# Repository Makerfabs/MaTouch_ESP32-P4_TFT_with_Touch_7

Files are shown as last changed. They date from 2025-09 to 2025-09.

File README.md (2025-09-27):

If you encounter the following error when compiling under Windows, please try enabling Windows long path support.
```txt
\MaTouch_ESP32-P4_TFT_with_Touch_7\examples\esp_brookesia_phone\managed_components\espressif__esp_wifi_remote\dummy_src.c.obj.d: No such file or directory
```

do :

```cmd
# Open PowerShell with administrator privileges
reg add "HKLM\SYSTEM\CurrentControlSet\Control\FileSystem" /v LongPathsEnabled /t REG_DWORD /d 1
```

Restart the system.

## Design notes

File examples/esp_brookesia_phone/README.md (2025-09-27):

# ESP_Brookesia Phone

[中文版本](./README_CN.md)

This example, based on [ESP_Brookesia](https://github.com/espressif/esp-brookesia), demonstrates an Android-like interface that includes many different applications. The example utilizes the development board's MIPI-DSI, MIPI-CSI, ESP32-C6, SD card, and audio interfaces. Based on this example, a use case can be created using ESP_Brookesia, enabling efficient development of multimedia applications.

## Getting Started

### ESP-IDF Required

- This example supports ESP-IDF release/v5.4 and later branches. By default, it runs on ESP-IDF release/v5.4.
- Please follow the [ESP-IDF Programming Guide](https://docs.espressif.com/projects/esp-idf/en/latest/esp32/get-started/index.html) to set up the development environment. **We highly recommend** you [Build Your First Project](https://docs.espressif.com/projects/esp-idf/en/latest/esp32/get-started/index.html#build-your-first-project) to get familiar with ESP-IDF and make sure the environment is set up correctly.

### Configuration

Run ``idf.py menuconfig`` and go to ``Board Support Package(ESP32-P4)``:

```
menuconfig > Component config > Board Support Package
```

To use the SD card and enable the "Recorder" APP, "Camera" APP, run ``idf.py menuconfig`` and then select ``Example Configurations`` > ``Enable SD Card``

## How to Use the Example

### Build and Flash the Example

Build the project and flash it to the board, then run monitor tool to view serial output (replace `PORT` with your board's serial port name):

```c
idf.py -p PORT flash monitor
```

To exit the serial monitor, type ``Ctrl-]``.

See the [ESP-IDF Getting Started Guide](https://docs.espressif.com/projects/esp-idf/en/latest/get-started/index.html) for full steps to configure and use ESP-IDF to build projects.

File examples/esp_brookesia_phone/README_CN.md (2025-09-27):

# ESP_Brookesia Phone

[英文版本](./README.md)

该示例基于 [ESP_Brookesia](https://github.com/espressif/esp-brookesia)，展示了一个类似 Android 的界面，其中包含许多不同的应用程序。该示例使用了开发板的 MIPI-DSI 接口、MIPI-CSI 接口、ESP32-C6、SD 卡和音频接口。基于此示例，可以基于 ESP_Brookesia 创建一个使用案例，从而高效开发多媒体应用程序。

## 快速入门

### ESP-IDF 要求

- 此示例支持 ESP-IDF release/v5.4 及以上版本。默认情况下，在 ESP-IDF release/v5.4 上运行。
- 请参照 [ESP-IDF 编程指南](https://docs.espressif.com/projects/esp-idf/zh_CN/latest/esp32/get-started/index.html) 设置开发环境。**强烈推荐** 通过 [编译第一个工程](https://docs.espressif.com/projects/esp-idf/zh_CN/latest/esp32/get-started/index.html#id8) 来熟悉 ESP-IDF，并确保环境设置正确。

### 配置

运行 ``idf.py menuconfig`` 并修改 ``Board Support Package(ESP32-P4)`` 配置：

```
menuconfig > Component config > Board Support Package
```

若要使用 SD 卡并启用 "Recorder" APP，“Camera” APP，请运行 ``idf.py menuconfig`` 然后选择 ``Example Configurations`` > ``Enable SD Card``

## 如何使用示例

### 编译和烧录示例

编译项目并将其烧录到开发板上，运行监视工具可查看串行端口输出（将 `PORT` 替换为所用开发板的串行端口名）：

```c
idf.py -p PORT flash monitor
```

输入``Ctrl-]`` 可退出串口监视。

有关配置和使用 ESP-IDF 来编译项目的完整步骤，请参阅 [ESP-IDF 快速入门指南](https://docs.espressif.com/projects/esp-idf/zh_CN/latest/esp32/get-started/index.html) 。

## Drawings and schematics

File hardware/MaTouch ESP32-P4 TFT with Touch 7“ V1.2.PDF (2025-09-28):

# MCU

# Mic&Speak

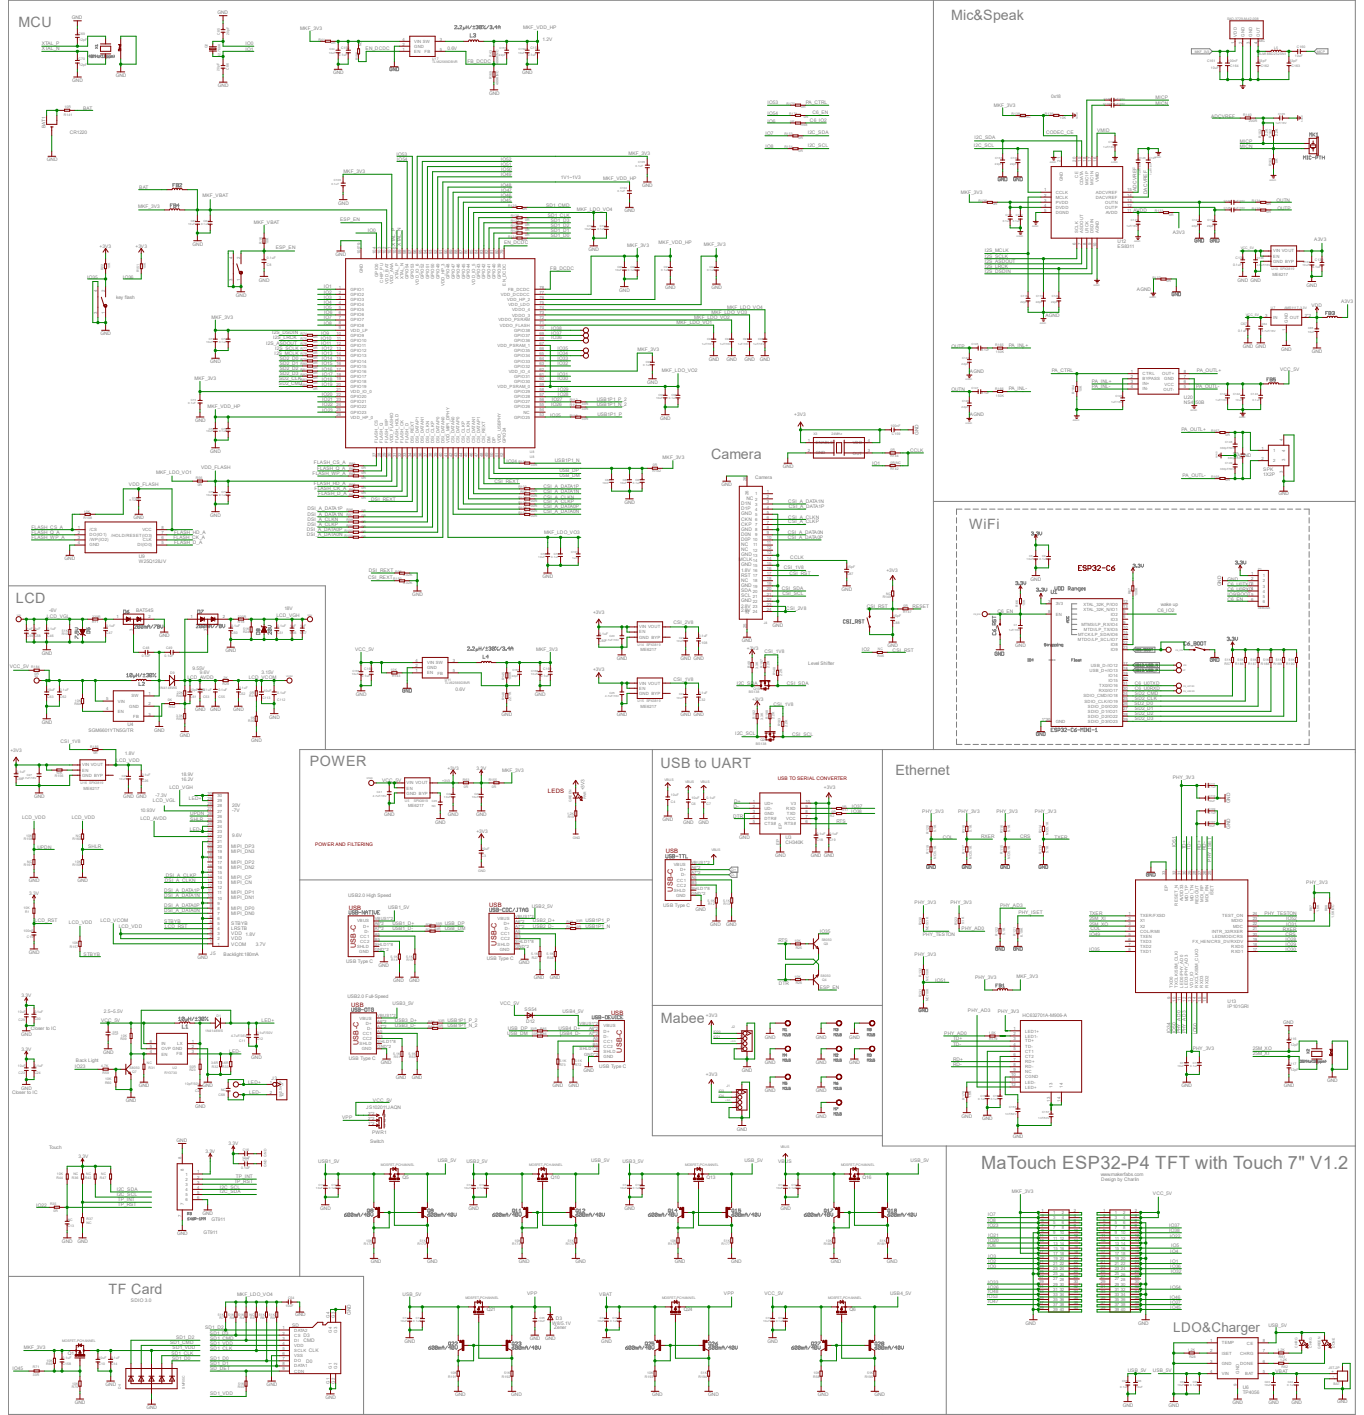
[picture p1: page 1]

USB TO SERIAL CONVERTER

GND
Design by Charlin MaTouch ESP32-P4 TFT with Touch 7" V1.2

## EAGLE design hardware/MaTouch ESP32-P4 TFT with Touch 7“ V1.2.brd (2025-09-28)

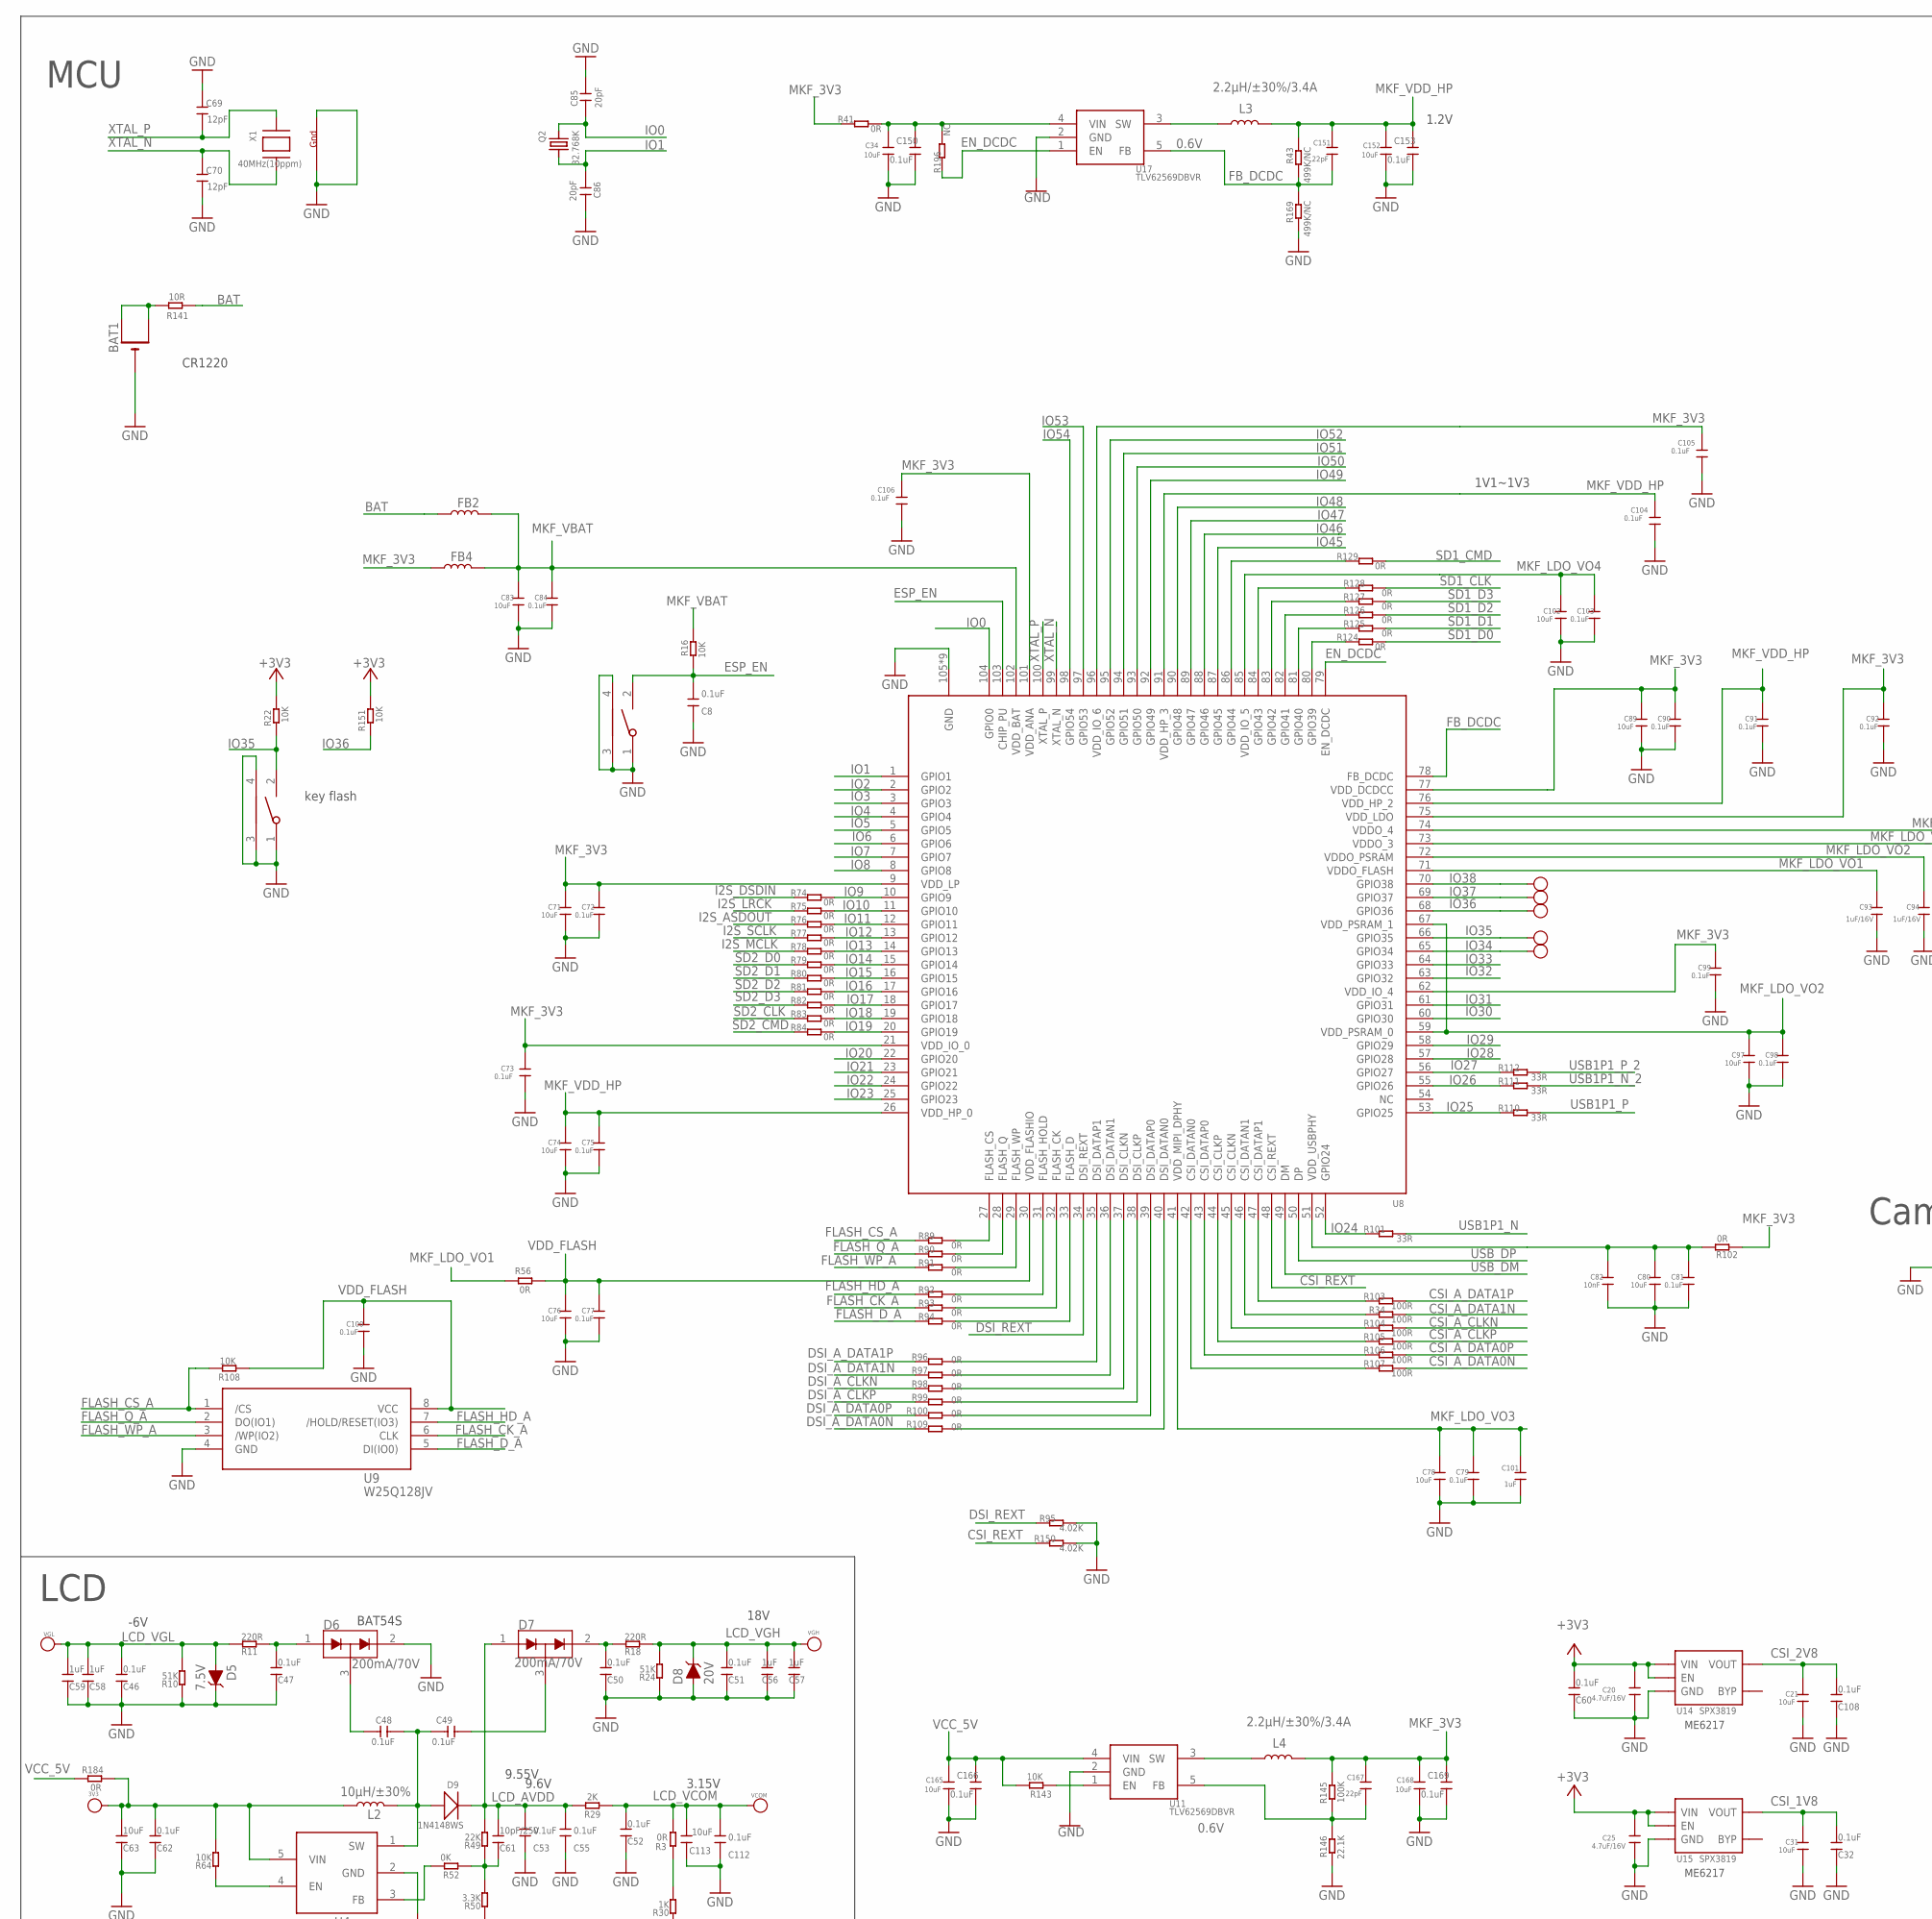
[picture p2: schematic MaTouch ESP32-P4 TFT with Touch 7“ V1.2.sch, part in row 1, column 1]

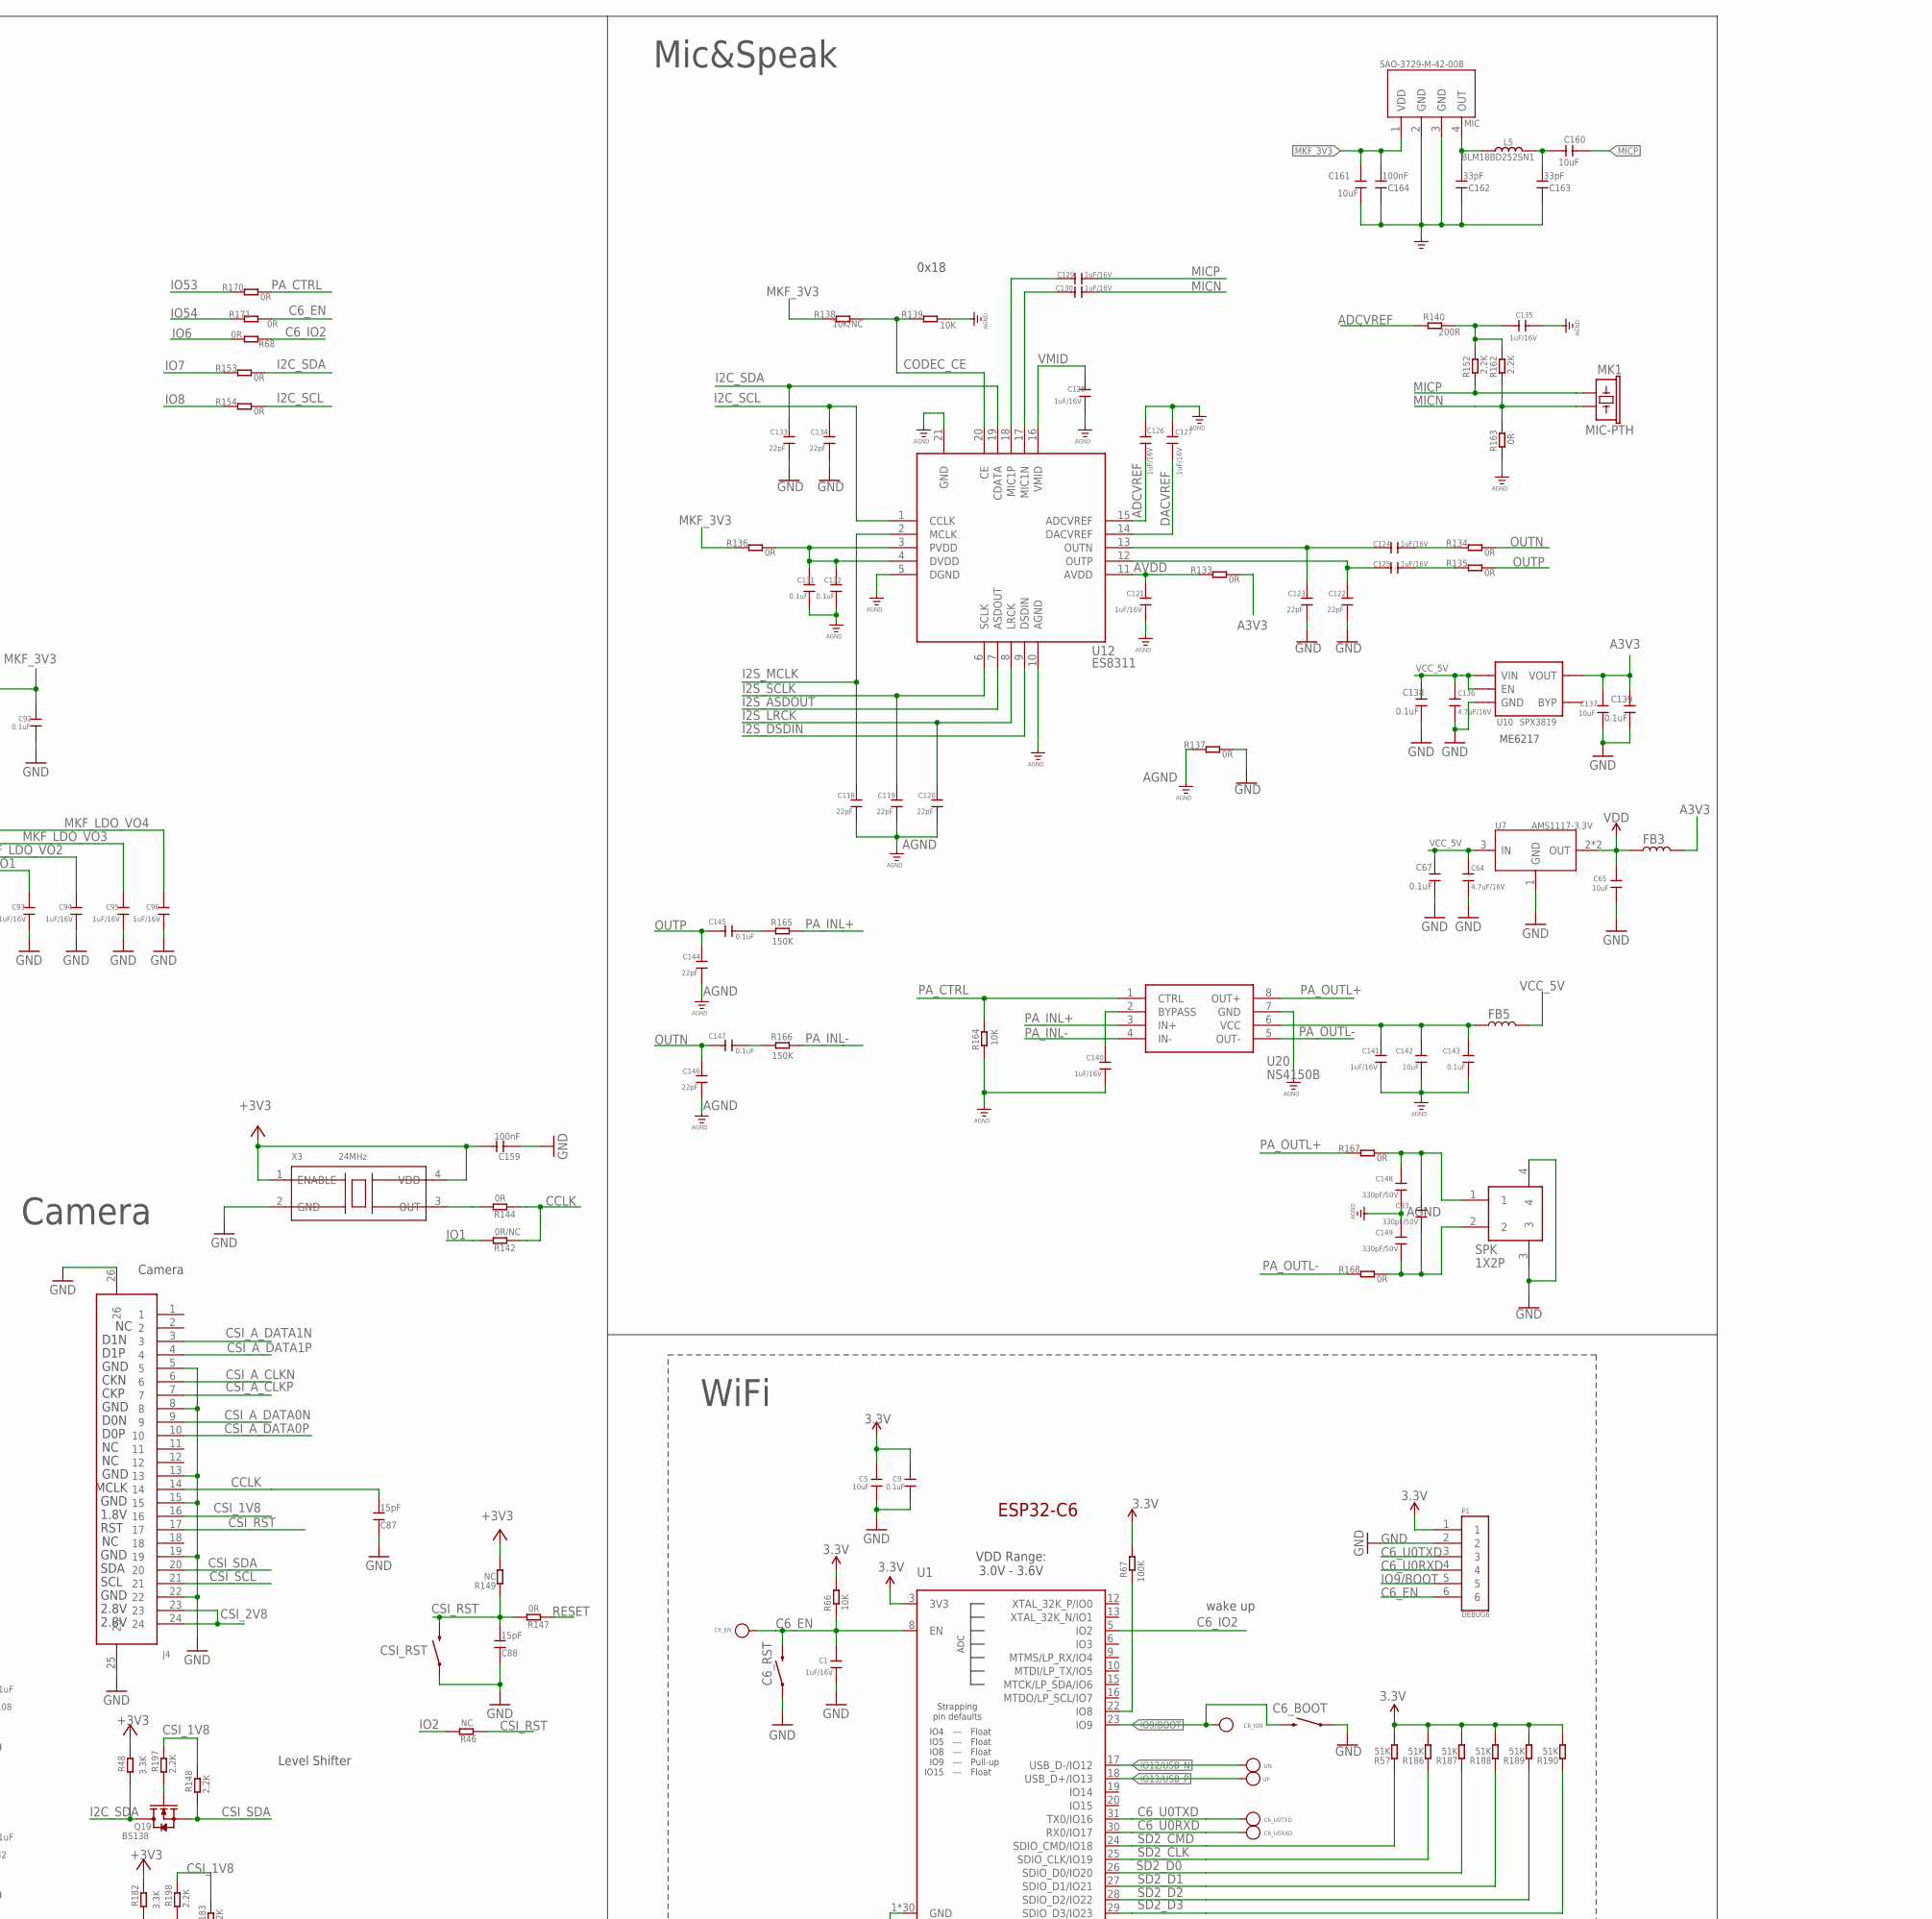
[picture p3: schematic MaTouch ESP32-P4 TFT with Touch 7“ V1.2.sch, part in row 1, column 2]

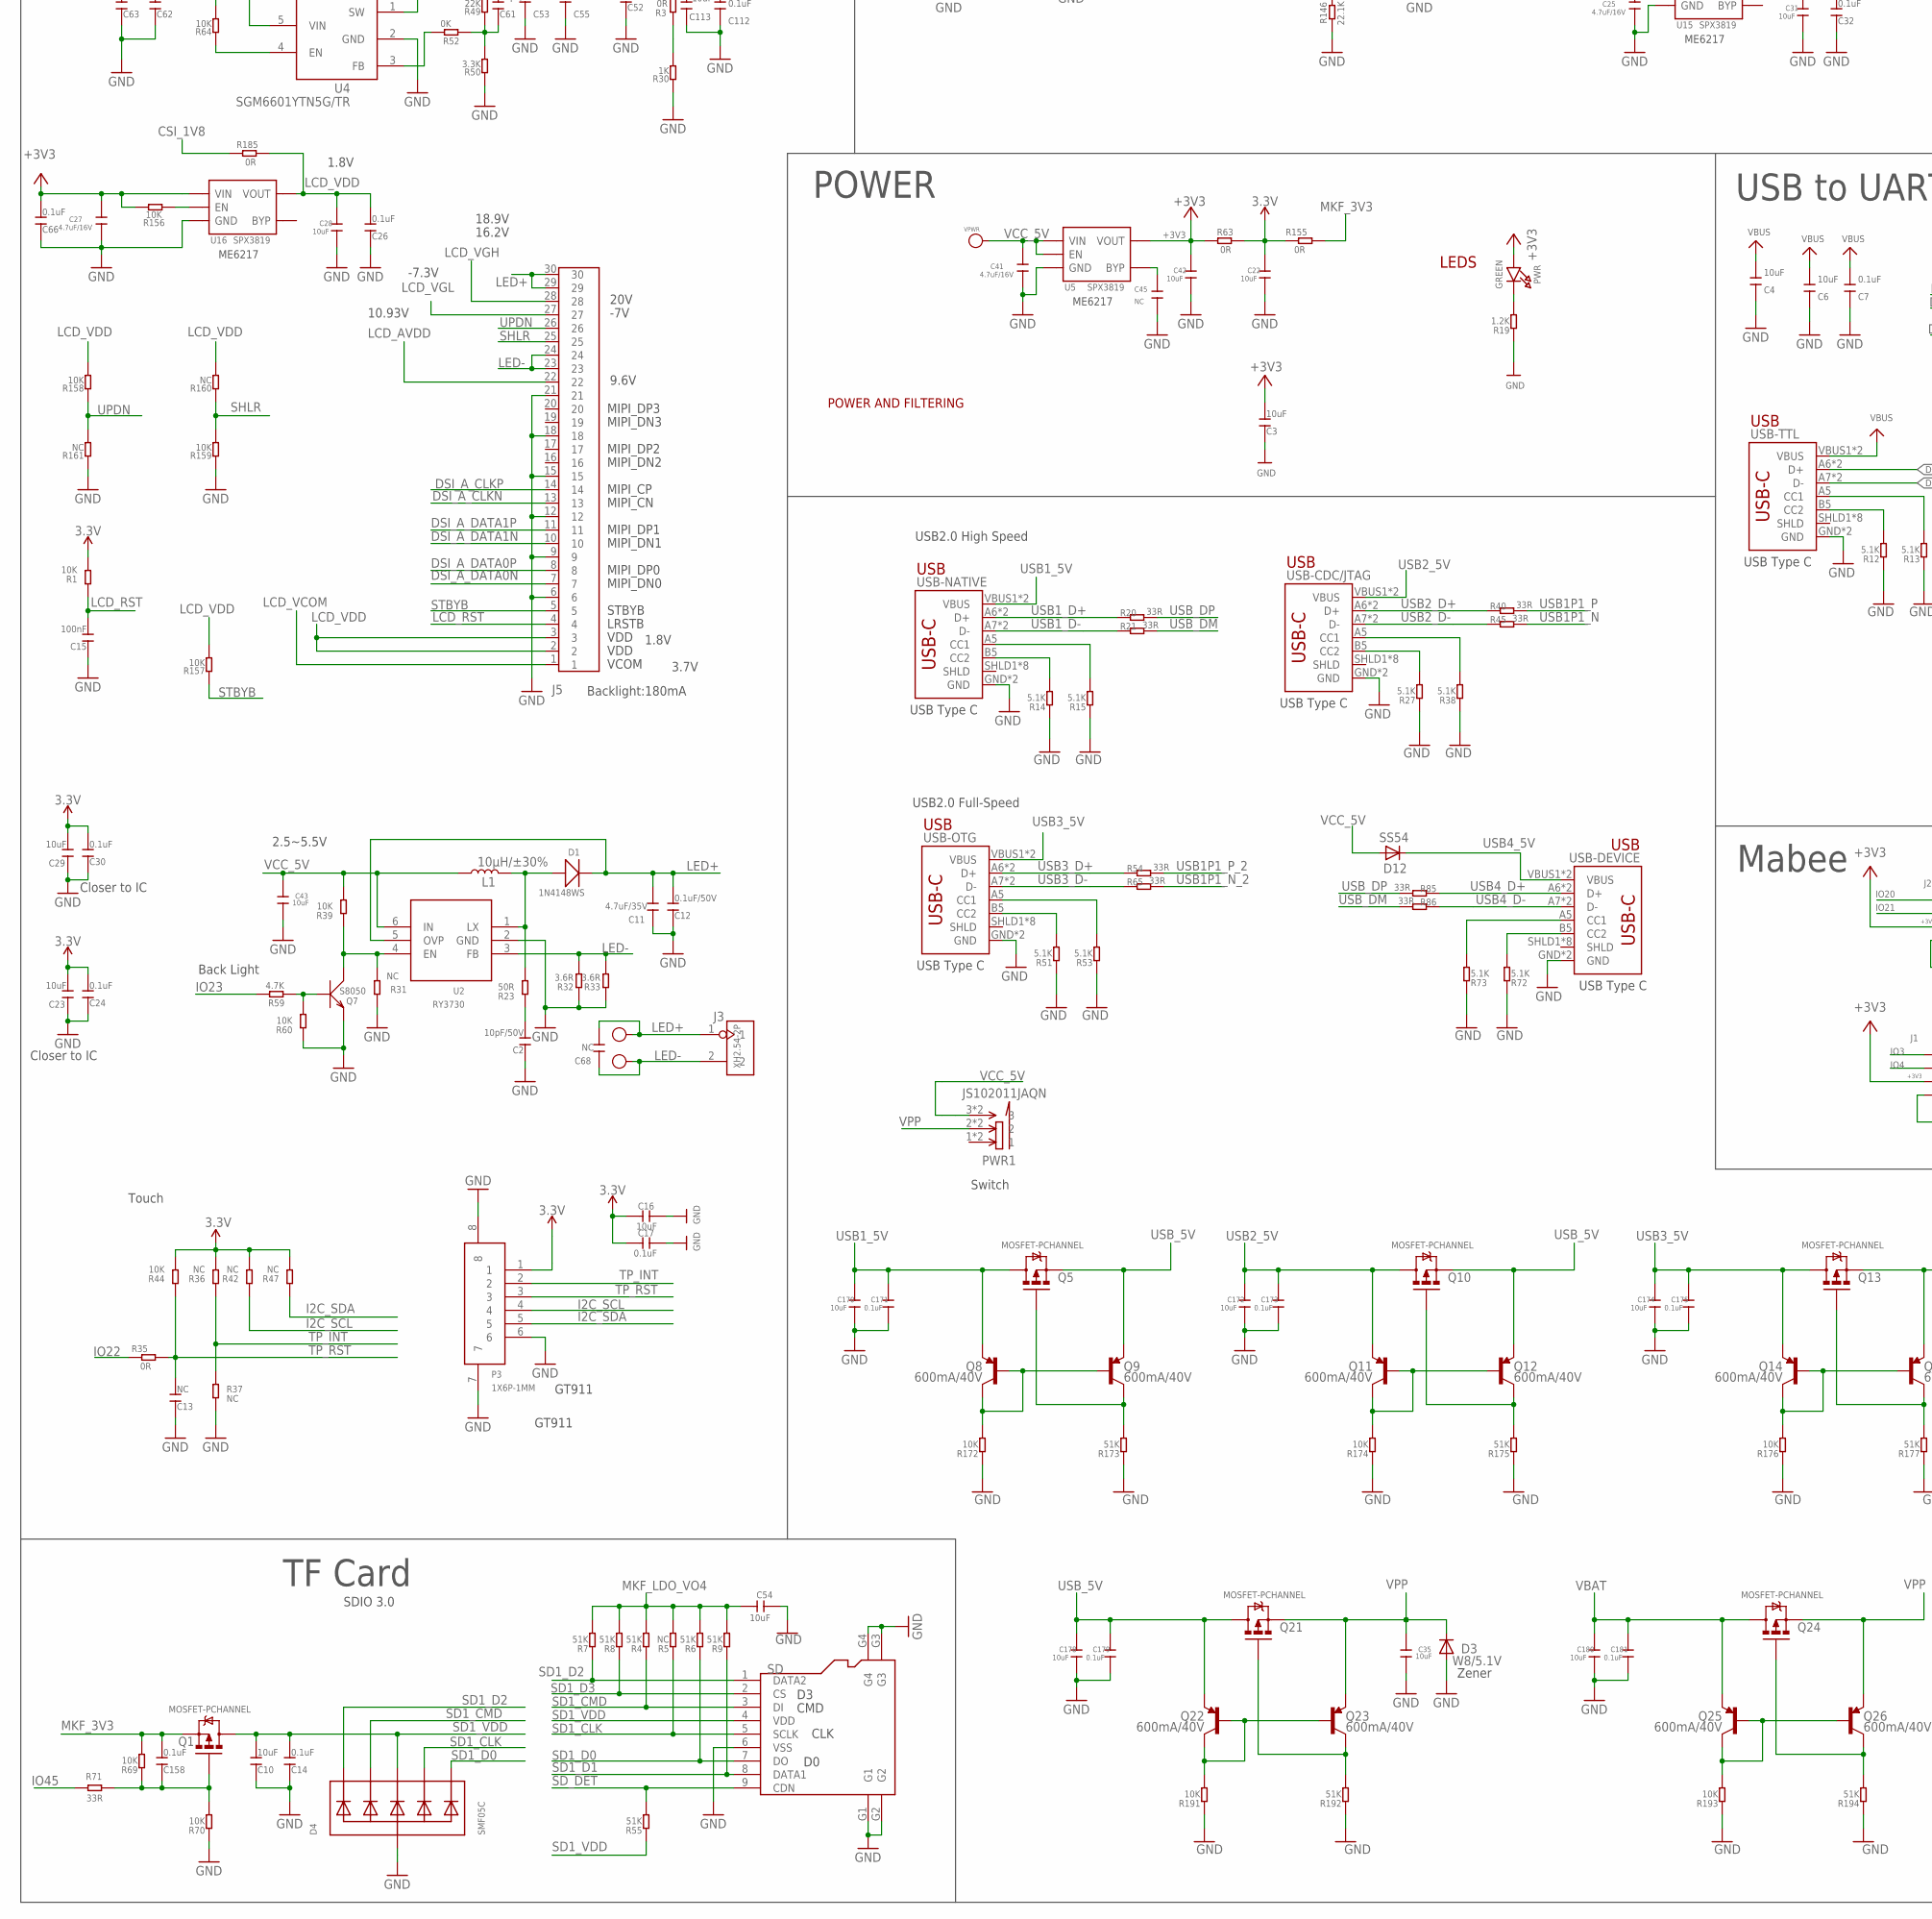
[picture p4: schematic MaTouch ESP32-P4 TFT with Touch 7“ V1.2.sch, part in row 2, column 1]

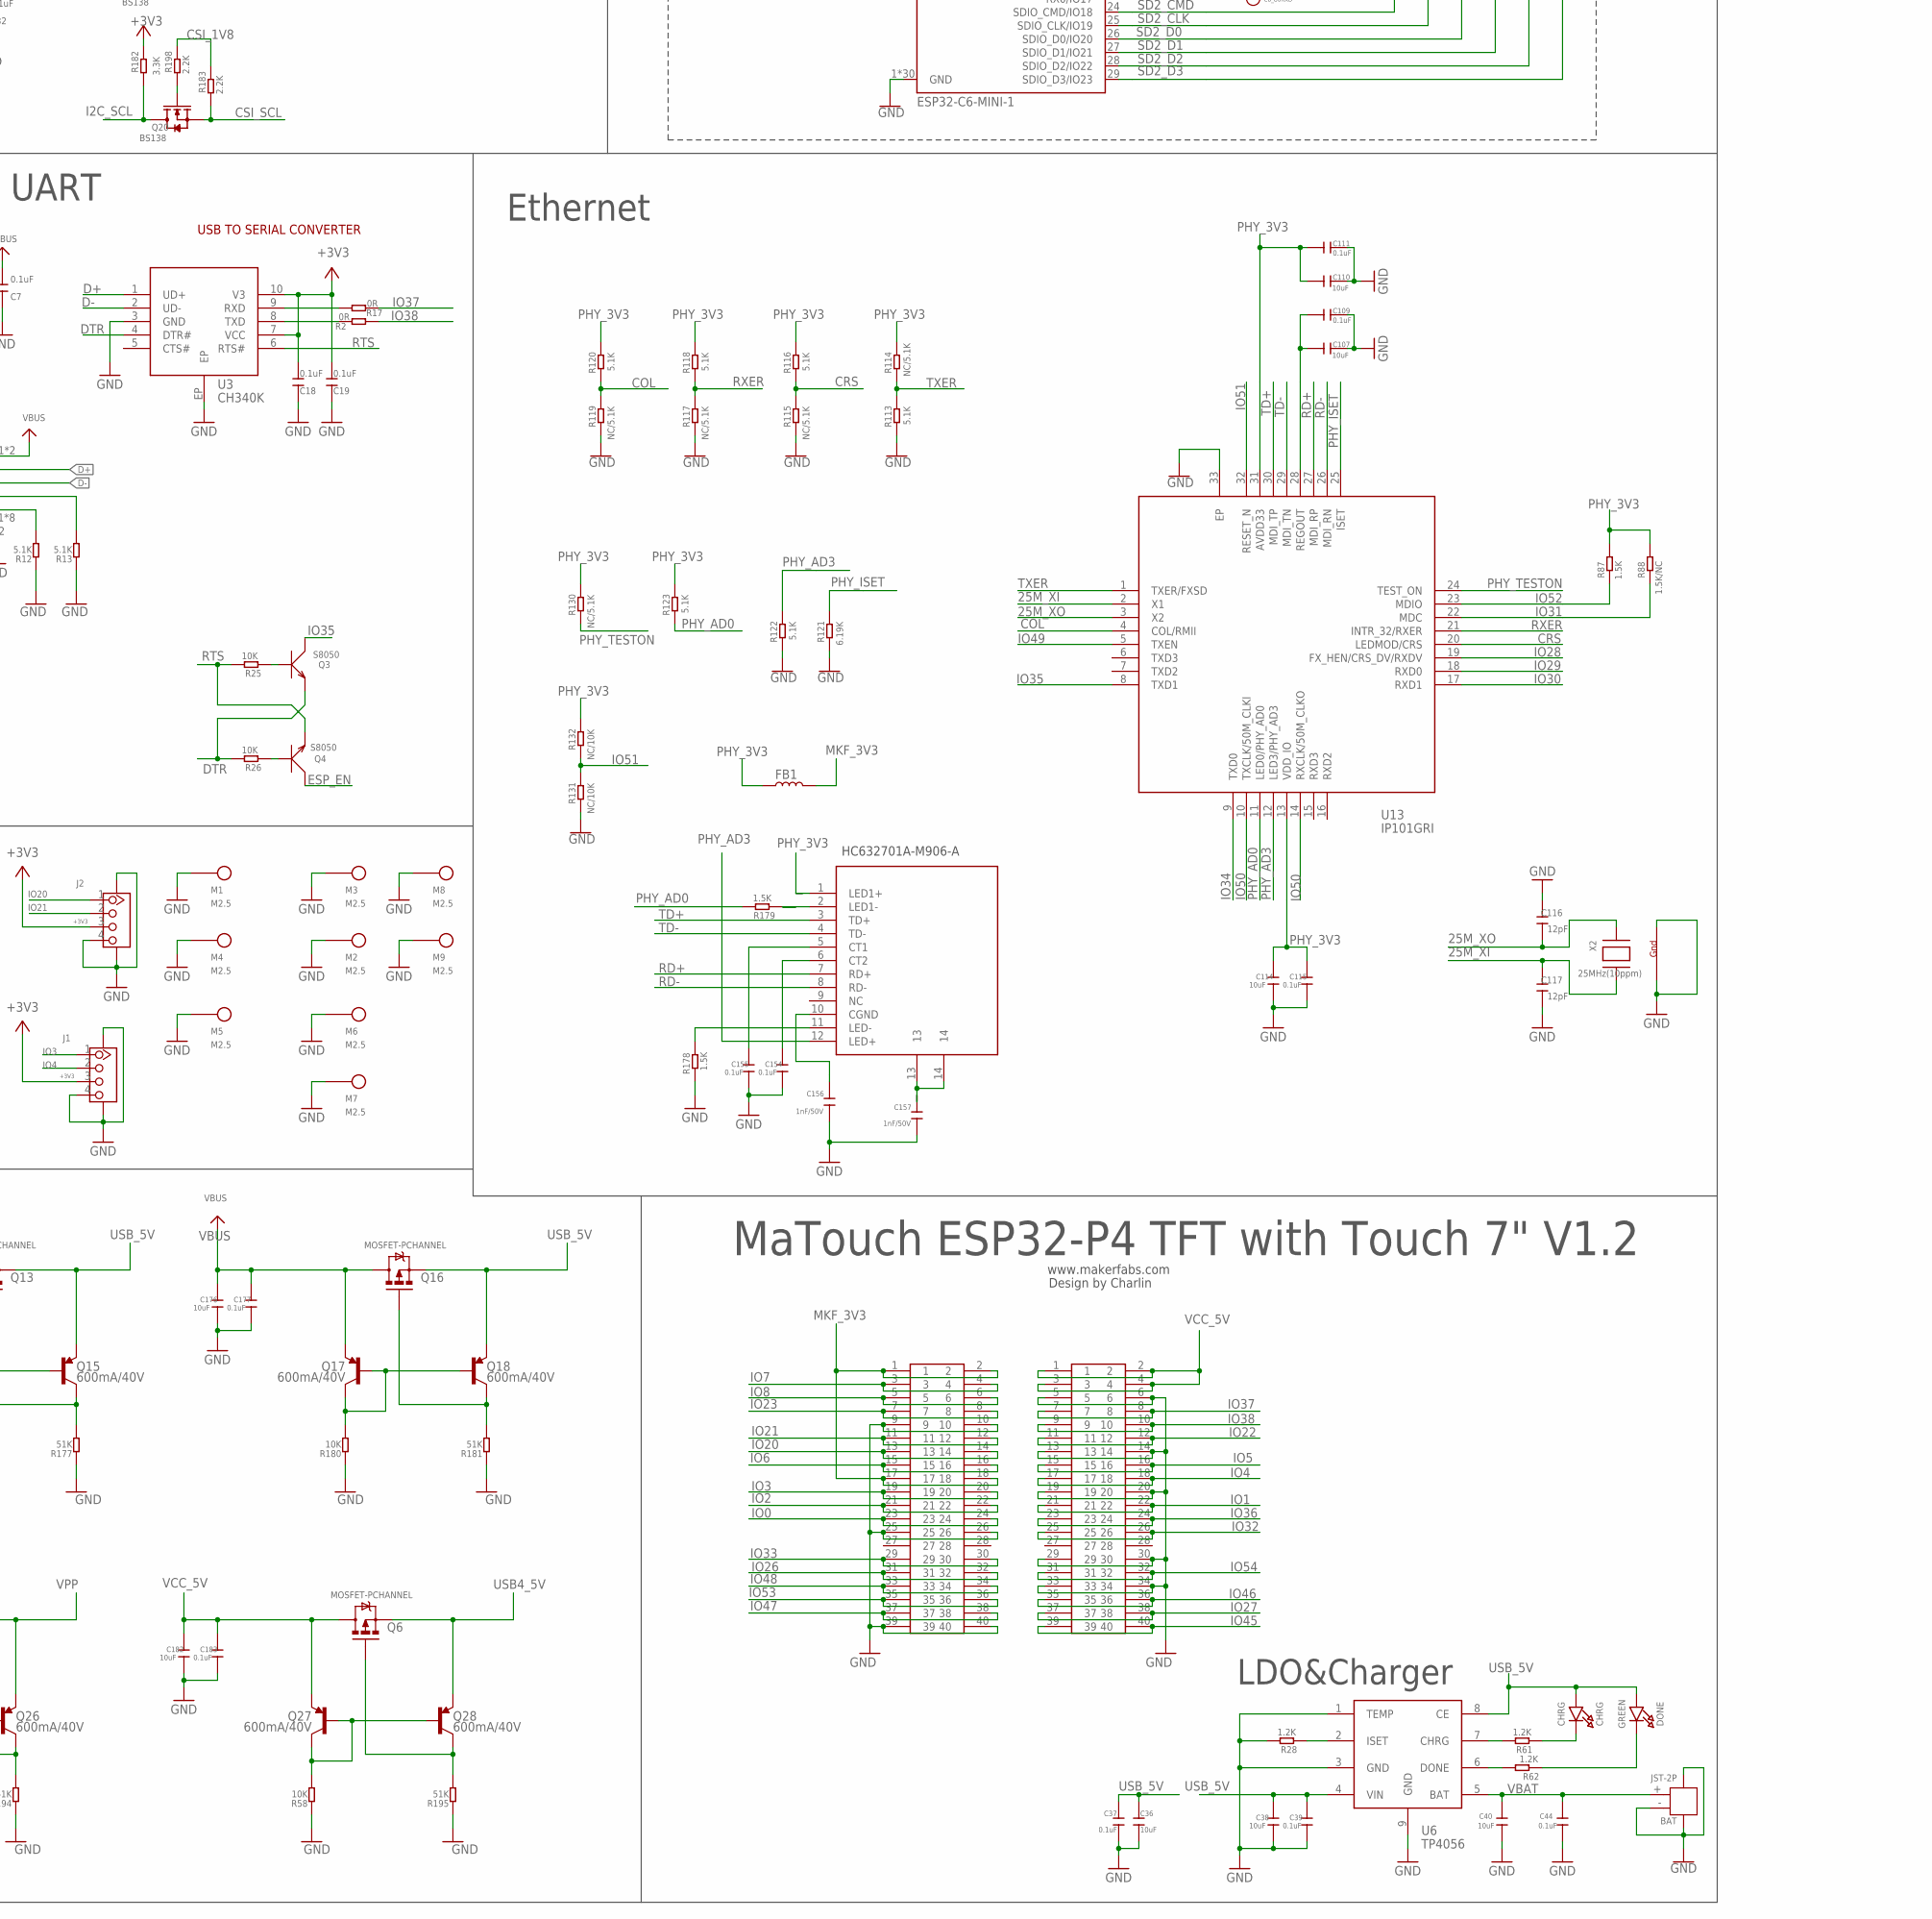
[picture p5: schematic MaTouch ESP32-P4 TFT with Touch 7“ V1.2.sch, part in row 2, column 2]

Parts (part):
3V3: PAD-TEST-POINT-CIRCLE'4545'; TP_4545; PARTNO DNP
BAT: JST-2P; HW2-SMD-2.0-90D
BAT1: CR1220SMT; CR1220-SMD
BOOT: TS24CA; 2*4*3.5MM
C1, C93, C94, C95, C96, C121, C124, C125, C126, C127, C128, C129, C130, C135, C140, C141: 1uF/16V; C0603
C2: 10pF/50V; DISCRETE_C0603
C3, C4, C6, C10, C16, C23, C29, C54, C63, C113: 10uF; DISCRETE_C0603
C5, C21, C22, C28, C31, C34, C35, C36, C38, C40, C42, C43, C65, C71, C74, C76, C78, C80, C83, C89, C97, C102, C107, C110, C114, C137, C142, C152, C160, C161, C165, C168, C170, C172, C174, C176, C178, C180, C182: 10uF; C0603
C6_BOOT, C6_RST: MOMENTARY-SWITCH-SPST-SMD-4.6X2.8MM; TACTILE_SWITCH_SMD_4.6X2.8MM
C6_EN, C6_IO9, C6_U0RXD, C6_U0TXD: PAD-TEST-POINT-CIRCLE'4545'; TP_4545; PARTNO DNP
C7, C8, C14, C17, C18, C19, C24, C26, C30, C32, C46, C47, C48, C49, C50, C51, C52, C53, C55, C60, C62, C66, C108, C112, C158: 0.1uF; DISCRETE_C0603
C9, C37, C39, C44, C67, C72, C73, C75, C77, C79, C81, C84, C90, C91, C92, C98, C99, C100, C103, C104, C105, C106, C109, C111, C115, C131, C132, C138, C139, C143, C145, C147, C150, C153, C154, C155, C166, C169, C171, C173, C175, C177, C179, C181, C183: 0.1uF; C0603
C11: 4.7uF/35V; DISCRETE_C1206
C12: 0.1uF/50V; DISCRETE_C0603
C13: NC; DISCRETE_C0603
C15: 100nF; DISCRETE_C0603
C20, C25, C27, C41, C64, C136: 4.7uF/16V; C0603
C33, C148, C149: 330pF/50V; C0603
C45: NC; C0603
C56, C57, C58, C59: 1uF; DISCRETE_C0603
C61: 10pF/25V; DISCRETE_C0603
C68: NC; DISCRETE_C1206
C69, C70, C116, C117: 12pF; DISCRETE_C0402
C82: 10nF; C0603
C85, C86: 20pF; DISCRETE_C0603
C87, C88: 15pF; DISCRETE_C0603
C101: 1uF; C0603
C118, C119, C120, C122, C123, C133, C134, C144, C146, C151, C167: 22pF; C0603
C156, C157: 1nF/50V; C0603
C159: 100nF; C0402
C162, C163: 33pF; C0603
C164: 100nF; C0603
CHRG: CHRG; CHIPLED_0805_NOOUTLINE
CSI_RST: MOMENTARY-SWITCH-SPST-SMD-4.6X2.8MM; TACTILE_SWITCH_SMD_4.6X2.8MM
D1, D9: 1N4148WS; SOD323
D3: W8/5.1V; SOD123
D4: SMF05C; SOT363
D5: 7.5V; SOD-323
D6, D7: 200mA/70V; SOT23-3
D8: 20V; SOD-323
D12: SS54; DO-214AC
D+: TEST-POINT'4545'; TP-D45MIL; PARTNO DNP
D-: TEST-POINT'4545'; TP-D45MIL; PARTNO DNP
DONE: GREEN; CHIPLED_0805_NOOUTLINE
FB1, FB2, FB3, FB4, FB5: INDUCTORFB-30OHM; 0603
IO34, IO35, IO36, IO37, IO38: TEST-POINT'4545'; TP-D45MIL; PARTNO DNP
J1, J2: GROVE-CONNECTOR-SMD'90D'; HW4-SMD-2.0-90D
J3: XH2.54-2P
J4: FPC-24P; SMD26-50P-1760L450W
J5: FPC-SOCKET-0.5-30P; 30P-0.5-90D-18.4X5.0
J6, J10: CON2X20-254P-A; SMD2X20-254P-5080L750W920H
J7: HR961160C
L1, L2: 10µH/±30%; CR54
L3, L4: 2.2µH/±30%/3.4A; CR54
L5: BLM18BD252SN1; L0603
M1, M2, M3, M4, M5, M6, M7, M8, M9: M2.5
MIC: SAO-3729-M-42-008; MIC4-SMD-3.76X2.95MM
MK1: MIC-PTH; MICROPHONE-PTH-9.7MM
P1: DEBUG6; DEBUG*6
P3: 1X6P-1MM; 1*6P-SMT1MM
PWR: GREEN; CHIPLED_0805_NOOUTLINE
PWR1: JS102011JAQN; SMD-6-2.5MM
Q1, Q5, Q6, Q10, Q13, Q16, Q21, Q24: MOSFET-PCHANNEL; SOT23-3
Q2: 32.768K; XTAL3215
Q3, Q4, Q7: S8050; SOT23
Q8, Q9, Q11, Q12, Q14, Q15, Q17, Q18, Q22, Q23, Q25, Q26, Q27, Q28: 600mA/40V; SOT23-3
Q19, Q20: BS138; SOT23
R1, R39, R44, R58, R60, R64, R69, R70, R108, R156, R157, R158, R159, R172, R174, R176, R180, R191, R193: 10K; DISCRETE_R0603
R2, R17, R35, R41, R56, R63, R68, R74, R75, R76, R77, R78, R79, R80, R81, R82, R83, R84, R89, R90, R91, R92, R93, R94, R96, R97, R98, R99, R100, R102, R109, R124, R125, R126, R127, R128, R129, R133, R134, R135, R136, R137, R144, R147, R153, R154, R155, R163, R167, R168, R170, R171, R184, R185: 0R; R0603
R3: 0R; DISCRETE_R0603
R4, R6, R7, R8, R9, R10, R24, R55, R57, R173, R175, R177, R181, R186, R187, R188, R189, R190, R192, R194, R195: 51K; DISCRETE_R0603
R5, R31, R36, R37, R42, R47, R149, R160, R161: NC; DISCRETE_R0603
R11, R18: 220R; DISCRETE_R0603
R12, R13, R14, R15, R27, R38, R51, R53, R72, R73: 5.1K; DISCRETE_R0603
R16, R22, R25, R26, R66, R139, R143, R151, R164: 10K; R0603
R19: 1.2K; DISCRETE_R0603
R20, R21, R40, R45, R54, R65, R71, R85, R86, R101, R110, R111, R112: 33R; R0603
R23: 50R; DISCRETE_R0603
R28, R61, R62: 1.2K; R0603
R29: 2K; DISCRETE_R0603
R30: 1K; DISCRETE_R0603
R32, R33: 3.6R; DISCRETE_R0603
R34, R103, R104, R105, R106, R107: 100R; R0603
R43, R169: 499K/NC; R0603
R46, R196: NC; R0603
R48, R182: 3.3K; R0603
R49: 22K; DISCRETE_R0603
R50: 3.3K; DISCRETE_R0603
R52: 0K; DISCRETE_R0603
R59: 4.7K; DISCRETE_R0603
R67, R145: 100K; R0603
R87, R178, R179: 1.5K; R0603
R88: 1.5K/NC; R0603
R95, R150: 4.02K; R0603
R113, R116, R118, R120, R122, R123: 5.1K; R0603
R114, R115, R117, R119, R130: NC/5.1K; R0603
R121: 6.19K; R0603
R131, R132: NC/10K; R0603
R138: 10K/NC; R0603
R140: 200R; R0603
R141: 10R; R0603
R142: 0R/NC; R0603
R146: 22.1K; R0603
R148, R152, R162, R183, R197, R198: 2.2K; R0603
R165, R166: 150K; R0603
RST: TS24CA; 2*4*3.5MM
SD: HOLDER-MICROSD-9P; 9P-SMD-W/-RING
SPK: 1X2P; 1X2P-SMT1.25MM
U1: ESP32-C6-MINI-1
U2: RY3730; SOT23-6
U3: CH340K; ESOP-10-EP-150MIL
U4: SGM6601YTN5G/TR; SOT-23-5
U5, U10, U14, U15, U16: SPX3819; SOT23-5
U6: TP4056; SOP8-1.27P
U7: AMS1117-3.3V; SOT89
U8: ESP32-P4; QFN105-35P-500L500W
U9: W25Q128JV; SOIC-8-208MIL
U11, U17: TLV62569DBVR; SOT23-5-95P-300L300W
U12: ES8311; QFN20-40P-300L300W55H
U13: IP101GRI; QFN32-40P-400W400L
U20: NS4150B; MSOP8-65P-490L300W110H
UN: PAD-TEST-POINT-CIRCLE'4545'; TP_4545; PARTNO DNP
UP: PAD-TEST-POINT-CIRCLE'4545'; TP_4545; PARTNO DNP
USB-CDC/JTAG: USB_C5; USB-C-16P-5
USB-DEVICE: USB_C5; USB-C-16P-5
USB-NATIVE: USB_C5; USB-C-16P-5
USB-OTG: USB_C5; USB-C-16P-5
USB-TTL: USB_C5; USB-C-16P-5
VCOM: PAD-TEST-POINT-CIRCLE'4545'; TP_4545
VGH: PAD-TEST-POINT-CIRCLE'4545'; TP_4545; PARTNO DNP
VGL: PAD-TEST-POINT-CIRCLE'4545'; TP_4545; PARTNO DNP
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

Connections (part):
3.3V: C5.1, C9.1, C16.2, C17.2, C22.1, C23.2, C24.2, C29.2, C30.2, P1.1, P3.1, R1.2, R36.2, R42.2, R44.2, R47.2, R57.2, R63.2, R66.2, R67.2, R155.1, R186.2, R187.2, R188.2, R189.2, R190.2, U1.3 (3V3)
25M_XI: C117.2, U13.2 (X1), X2.3 (X2)
25M_XO: C116.1, U13.3 (X2), X2.1 (X1)
+3V3: C3.2, C18.2, C19.2, C20.1, C25.1, C27.1, C42.1, C60.2, C66.2, C159.2, J1.3, J2.3, PWR.A, R22.2, R48.2, R63.1, R149.2, R151.2, R156.2, R182.2, U3.7 (VCC), U3.10 (V3), U5.5 (VOUT), U14.1 (VIN), U14.3 (EN), U15.1 (VIN), U15.3 (EN), U16.1 (VIN), X3.1 (ENABLE), X3.4 (VDD)
A3V3: C137.1, C139.2, FB3.2, R133.2, U10.5 (VOUT)
ADCVREF: C126.2, R140.1, U12.15 (ADCVREF)
AGND: C118.2, C119.2, C120.2, C121.2, C126.1, C127.1, C128.2, C131.2, C132.2, C135.2, C140.2, C141.2, C142.2, C143.2, C144.2, C146.2, C148.2, C149.1, C161.1, C162.2, C163.2, C164.2, MIC.2 (GND), MIC.3 (GND), R137.1, R139.2, R163.1, R164.1, U12.5 (DGND), U12.10 (AGND), U12.21 (GND), U20.7 (GND)
AVDD: C121.1, R133.1, U12.11 (AVDD)
BAT: FB2.1, R141.1
C6_EN: C1.1, C6_EN.T, C6_RST.3 (2), C6_RST.4 (2), P1.6, R66.1, R171.2, U1.8 (EN)
C6_IO2: R68.1, U1.5 (IO2)
C6_U0RXD: C6_U0RXD.T, P1.4, U1.30 (RX0/IO17)
C6_U0TXD: C6_U0TXD.T, P1.3, U1.31 (TX0/IO16)
CCLK: C87.2, J4.14, R142.1, R144.1
CODEC_CE: R138.2, R139.1, U12.20 (CE)
COL: R119.2, R120.1, U13.4 (COL/RMII)
CRS: R115.2, R116.1, U13.20 (LEDMOD/CRS)
CSI_1V8: C31.1, C32.2, J4.16, R148.2, R183.2, R185.1, R197.2, R198.2, U15.5 (VOUT)
CSI_2V8: C21.1, C108.2, J4.23, J4.24, U14.5 (VOUT)
CSI_A_CLKN: J4.6, R104.2
CSI_A_CLKP: J4.7, R105.2
CSI_A_DATA0N: J4.9, R107.2
CSI_A_DATA0P: J4.10, R106.2
CSI_A_DATA1N: J4.3, R34.2
CSI_A_DATA1P: J4.4, R103.2
CSI_REXT: R150.1, U8.48 (CSI_REXT)
CSI_RST: C88.2, CSI_RST.3 (2), CSI_RST.4 (2), J4.17, R46.1, R147.2, R149.1
CSI_SCL: J4.21, Q20.2 (S), R183.1
CSI_SDA: J4.20, Q19.2 (S), R148.1
D+: U3.1 (UD+), USB-TTL.A6 (D+), USB-TTL.B6 (D+)
D-: U3.2 (UD-), USB-TTL.A7 (D-), USB-TTL.B7 (D-)
DACVREF: C127.2, U12.14 (DACVREF)
DSI_A_CLKN: J5.13, R98.1
DSI_A_CLKP: J5.14, R99.1
DSI_A_DATA0N: J5.7, R109.1
DSI_A_DATA0P: J5.8, R100.1
DSI_A_DATA1N: J5.10, R97.1
DSI_A_DATA1P: J5.11, R96.1
DSI_REXT: R95.1, U8.34 (DSI_REXT)
DTR: Q3.2 (E), R26.2, U3.4 (DTR#)
EN_DCDC: R196.1, U8.79 (EN_DCDC), U17.1 (EN)
ESP_EN: C8.2, Q4.3 (C), R16.1, RST.2, U8.103 (CHIP_PU)
FB_DCDC: C151.2, R43.1, R169.2, U8.78 (FB_DCDC), U17.5 (FB)
FLASH_CK_A: R93.1, U9.6 (CLK)
FLASH_CS_A: R89.1, R108.2, U9.1 (/CS)
FLASH_D_A: R94.1, U9.5 (DI(IO0))
FLASH_HD_A: R92.1, U9.7 (/HOLD/RESET(IO3))
FLASH_Q_A: R90.1, U9.2 (DO(IO1))
FLASH_WP_A: R91.1, U9.3 (/WP(IO2))
GND: BAT.3, BAT.4, BAT.- (2), BAT1.-, BOOT.1, BOOT.3, BOOT.4, C1.2, C2.1, C3.1, C4.1, C5.2, C6.1, C6_BOOT.1, C6_BOOT.2 (1), C6_RST.1, C6_RST.2 (1), C7.1, C8.1, C9.2, C10.1, C11.1, C12.1, C13.1, C14.1, C15.1, C16.1, C17.1, C18.1, C19.1, C20.2, C21.2, C22.2, C23.1, C24.1, C25.2, C26.1, C27.2, C28.2, C29.1, C30.1, C31.2, C32.1, C34.2, C35.1, C36.1, C37.2, C38.2, C39.2, C40.2, C41.2, C42.2, C43.1, C44.2, C45.2, C46.1, C47.1, C50.1, C51.1, C52.1, C53.1, C54.1, C55.1, C56.1, C57.1, C58.1, C59.1, C60.1, C62.1, C63.1, C64.2, C65.2, C66.1, C67.1, C69.2, C70.1, C71.2, C72.2, C73.2, C74.2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
I2C_SCL: C134.1, P3.4, Q20.3 (D), R42.1, R154.2, R182.1, U12.1 (CCLK)
I2C_SDA: C133.1, P3.5, Q19.3 (D), R47.1, R48.1, R153.2, U12.19 (CDATA)
I2S_ASDOUT: R76.1, U12.7 (ASDOUT)
I2S_DSDIN: R74.1, U12.9 (DSDIN)
I2S_LRCK: C120.1, R75.1, U12.8 (LRCK)
I2S_MCLK: C118.1, R78.1, U12.2 (MCLK)
I2S_SCLK: C119.1, R77.1, U12.6 (SCLK)
IO0: C85.1, J6.23, J6.24, Q2.P$1 (1), U8.104 (GPIO0)
IO1: C86.1, J10.21, J10.22, Q2.P$2 (2), R142.2, U8.1 (GPIO1)
IO2: J6.21, J6.22, R46.2, U8.2 (GPIO2)
IO3: J1.1, J6.19, J6.20, U8.3 (GPIO3)
IO4: J1.2, J10.17, J10.18, U8.4 (GPIO4)
IO5: J10.15, J10.16, U8.5 (GPIO5)
IO6: J6.15, J6.16, R68.2, U8.6 (GPIO6)
IO7: J6.3, J6.4, R153.1, U8.7 (GPIO7)
IO8: J6.5, J6.6, R154.1, U8.8 (GPIO8)
IO9: R74.2, U8.10 (GPIO9)
IO9/BOOT: C6_BOOT.3 (2), C6_BOOT.4 (2), C6_IO9.T, P1.5, U1.23 (IO9)
IO10: R75.2, U8.11 (GPIO10)
IO11: R76.2, U8.12 (GPIO11)
IO12: R77.2, U8.13 (GPIO12)
IO12/USB_N: U1.17 (USB_D-/IO12), UN.T
IO13: R78.2, U8.14 (GPIO13)
IO13/USB_P: U1.18 (USB_D+/IO13), UP.T
IO14: R79.2, U8.15 (GPIO14)
IO15: R80.2, U8.16 (GPIO15)
IO16: R81.2, U8.17 (GPIO16)
IO17: R82.2, U8.18 (GPIO17)
IO18: R83.2, U8.19 (GPIO18)
IO19: R84.2, U8.20 (GPIO19)
IO20: J2.1, J6.13, J6.14, U8.22 (GPIO20)
IO21: J2.2, J6.11, J6.12, U8.23 (GPIO21)
IO22: J10.11, J10.12, R35.1, U8.24 (GPIO22)
IO23: J6.7, J6.8, R59.2, U8.25 (GPIO23)
IO24: R101.1, U8.52 (GPIO24)
IO25: R110.1, U8.53 (GPIO25)
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

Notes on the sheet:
www.makerfabs.com
Design by Charlin
USB
LEDS
POWER AND FILTERING
USB TO SERIAL CONVERTER
MaTouch ESP32-P4 TFT with Touch 7" V1.2
POWER
USB to UART
USB Type C
TF Card
GT911
Closer to IC
Back Light
Mabee
MCU
LDO&Charger
ME6217
BAT54S
key flash
CMD
CLK
2.5~5.5V
Zener
Camera
SDA
GND
MCLK
D1N
D1P
CKN
CKP
D0N
D0P
1.8V
RST
SCL
2.8V
Level Shifter
Touch

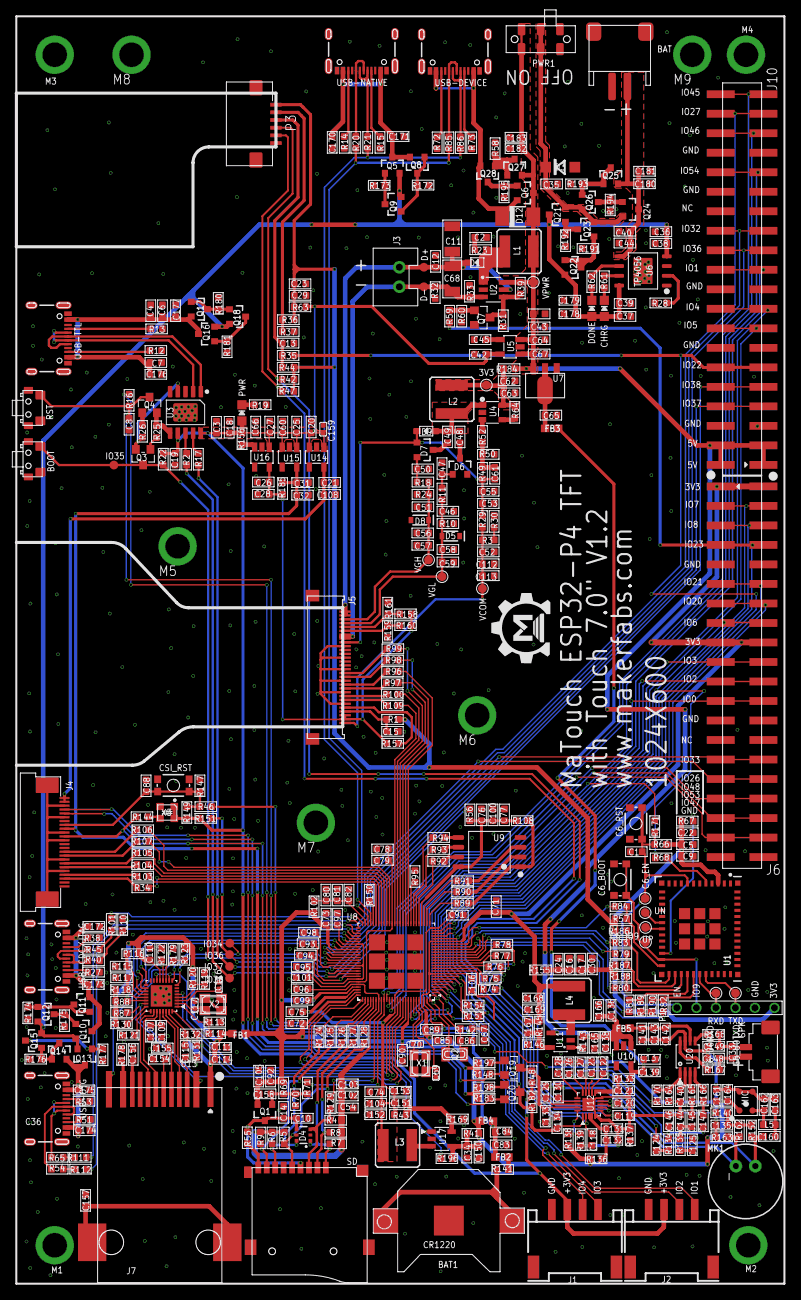
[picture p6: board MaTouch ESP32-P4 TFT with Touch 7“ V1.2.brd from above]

Board: 2 copper layers, 100.0 x 165.0 mm, 507 parts (0 on the bottom side), 301 nets.

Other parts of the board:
U$1: MAKERFABS_0.3

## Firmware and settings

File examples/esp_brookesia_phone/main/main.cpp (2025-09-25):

#include "freertos/FreeRTOS.h"
#include "freertos/task.h"
#include "nvs_flash.h"
#include "nvs.h"
#include "esp_log.h"
#include "esp_err.h"
#include "esp_check.h"
#include "esp_memory_utils.h"
#include "esp_heap_caps.h"
#include "lvgl.h"
#include "bsp/esp-bsp.h"
#include "bsp/display.h"
#include "bsp_board_extra.h"

#include "esp_brookesia.hpp"
#include "app_examples/phone/squareline/src/phone_app_squareline.hpp"
#include "apps.h"

static const char *TAG = "main";

extern "C" void app_main(void)
{
    esp_reset_reason_t reset_reason = esp_reset_reason();
    if (reset_reason == ESP_RST_SW || reset_reason == ESP_RST_PANIC) {
        ESP_LOGI(TAG, "Software or panic reset detected, adding delay for hardware stabilization");
        vTaskDelay(pdMS_TO_TICKS(100));
    }

    esp_err_t err = nvs_flash_init();
    if (err == ESP_ERR_NVS_NO_FREE_PAGES || err == ESP_ERR_NVS_NEW_VERSION_FOUND) {
        ESP_ERROR_CHECK(nvs_flash_erase());
        err = nvs_flash_init();
    }
    ESP_ERROR_CHECK(err);

    ESP_ERROR_CHECK(bsp_spiffs_mount());
    ESP_LOGI(TAG, "SPIFFS mount successfully");

#if CONFIG_EXAMPLE_ENABLE_SD_CARD
    ESP_ERROR_CHECK(bsp_sdcard_mount());
    ESP_LOGI(TAG, "SD card mount successfully");
#endif

    ESP_ERROR_CHECK(bsp_extra_codec_init());

    bsp_display_cfg_t cfg = {
        .lvgl_port_cfg = ESP_LVGL_PORT_INIT_CONFIG(),
        .buffer_size = BSP_LCD_H_RES * 50,
        .double_buffer = BSP_LCD_DRAW_BUFF_DOUBLE,
        .flags = {
            .buff_dma = true,
            .buff_spiram = false,
            .sw_rotate = false,
        }
    };
    bsp_display_start_with_config(&cfg);
    bsp_display_backlight_on();

    vTaskDelay(pdMS_TO_TICKS(50));

    bsp_display_lock(0);

    ESP_Brookesia_Phone *phone = new ESP_Brookesia_Phone();
    assert(phone != nullptr && "Failed to create phone");

    ESP_Brookesia_PhoneStylesheet_t *phone_stylesheet = new ESP_Brookesia_PhoneStylesheet_t ESP_BROOKESIA_PHONE_1024_600_DARK_STYLESHEET();
    ESP_BROOKESIA_CHECK_NULL_EXIT(phone_stylesheet, "Create phone stylesheet failed");
    ESP_BROOKESIA_CHECK_FALSE_EXIT(phone->addStylesheet(*phone_stylesheet), "Add phone stylesheet failed");
    ESP_BROOKESIA_CHECK_FALSE_EXIT(phone->activateStylesheet(*phone_stylesheet), "Activate phone stylesheet failed");

    assert(phone->begin() && "Failed to begin phone");

    // PhoneAppSquareline *smart_gadget = new PhoneAppSquareline();
    // assert(smart_gadget != nullptr && "Failed to create phone app squareline");
    // assert((phone->installApp(smart_gadget) >= 0) && "Failed to install phone app squareline");

    Calculator *calculator = new Calculator();
    assert(calculator != nullptr && "Failed to create calculator");
    assert((phone->installApp(calculator) >= 0) && "Failed to begin calculator");

    MusicPlayer *music_player = new MusicPlayer();
    assert(music_player != nullptr && "Failed to create music_player");
    assert((phone->installApp(music_player) >= 0) && "Failed to begin music_player");

    AppSettings *app_settings = new AppSettings();
    assert(app_settings != nullptr && "Failed to create app_settings");
    assert((phone->installApp(app_settings) >= 0) && "Failed to begin app_settings");

    Game2048 *game_2048 = new Game2048();
    assert(game_2048 != nullptr && "Failed to create game_2048");
    assert((phone->installApp(game_2048) >= 0) && "Failed to begin game_2048");

    Camera *camera = new Camera(1280, 720);
    assert(camera != nullptr && "Failed to create camera");
    assert((phone->installApp(camera) >= 0) && "Failed to begin camera");

#if CONFIG_EXAMPLE_ENABLE_SD_CARD
    // ESP_LOGW(TAG, "Using Video Player example requires inserting the SD card in advance and saving an MJPEG format video on the SD card");
    // AppVideoPlayer *app_video_player = new AppVideoPlayer();
    // assert(app_video_player != nullptr && "Failed to create app_video_player");
    // assert((phone->installApp(app_video_player) >= 0) && "Failed to begin app_video_player");

    // Recorder
    Recorder *record = new Recorder();
    assert(record != nullptr && "Failed to create record");
    assert((phone->installApp(record) >= 0) && "Failed to begin record");
#endif

    // usb test
    UsbTest *usb_test = new UsbTest();
    assert(usb_test != nullptr && "Failed to create usb_test");
    assert((phone->installApp(usb_test) >= 0) && "Failed to begin usb_test");

    // lcd test
    LcdTest *lcd_test = new LcdTest();
    assert(lcd_test != nullptr && "Failed to create lcd_test");
    assert((phone->installApp(lcd_test) >= 0) && "Failed to begin lcd_test");
    
    bsp_display_unlock();
}

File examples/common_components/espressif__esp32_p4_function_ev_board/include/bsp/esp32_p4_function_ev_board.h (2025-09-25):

/*
 * SPDX-FileCopyrightText: 2024 Espressif Systems (Shanghai) CO LTD
 *
 * SPDX-License-Identifier: Apache-2.0
 */

/**
 * @file
 * @brief ESP BSP: ESP32-P4 Function EV Board
 */

#pragma once

#include "sdkconfig.h"
#include "driver/gpio.h"
#include "driver/i2c_master.h"
#include "driver/sdmmc_host.h"
#include "driver/i2s_std.h"
#include "bsp/config.h"
#include "bsp/display.h"
#include "esp_codec_dev.h"

#if (BSP_CONFIG_NO_GRAPHIC_LIB == 0)
#include "lvgl.h"
#include "esp_lvgl_port.h"
#endif // BSP_CONFIG_NO_GRAPHIC_LIB == 0

/**************************************************************************************************
 *  BSP Capabilities
 **************************************************************************************************/

#define BSP_CAPS_DISPLAY        1
#define BSP_CAPS_TOUCH          1
#define BSP_CAPS_BUTTONS        0
#define BSP_CAPS_AUDIO          1
#define BSP_CAPS_AUDIO_SPEAKER  1
#define BSP_CAPS_AUDIO_MIC      1
#define BSP_CAPS_SDCARD         1
#define BSP_CAPS_IMU            0

/**************************************************************************************************
 *  ESP-BOX pinout
 **************************************************************************************************/
/* I2C */
#define BSP_I2C_SCL           (GPIO_NUM_8)
#define BSP_I2C_SDA           (GPIO_NUM_7)

/* Audio */
#define BSP_I2S_SCLK          (GPIO_NUM_12)
#define BSP_I2S_MCLK          (GPIO_NUM_13)
#define BSP_I2S_LCLK          (GPIO_NUM_10)
#define BSP_I2S_DOUT          (GPIO_NUM_9)
#define BSP_I2S_DSIN          (GPIO_NUM_11)
#define BSP_POWER_AMP_IO      (GPIO_NUM_53)

/* Display */
#if CONFIG_BSP_LCD_TYPE_1024_600
#define BSP_LCD_BACKLIGHT     (GPIO_NUM_23)
#define BSP_LCD_RST           (GPIO_NUM_27)
#define BSP_LCD_TOUCH_RST     (GPIO_NUM_22)
#define BSP_LCD_TOUCH_INT     (GPIO_NUM_NC)
#else
#define BSP_LCD_BACKLIGHT     (GPIO_NUM_23)
#define BSP_LCD_RST           (GPIO_NUM_NC)
#define BSP_LCD_TOUCH_RST     (GPIO_NUM_NC)
#define BSP_LCD_TOUCH_INT     (GPIO_NUM_NC)
#endif

/* uSD card */
#define BSP_SD_D0             (GPIO_NUM_39)
#define BSP_SD_D1             (GPIO_NUM_40)
#define BSP_SD_D2             (GPIO_NUM_41)
#define BSP_SD_D3             (GPIO_NUM_42)
#define BSP_SD_CMD            (GPIO_NUM_44)
#define BSP_SD_CLK            (GPIO_NUM_43)

#ifdef __cplusplus
extern "C" {
#endif

/**************************************************************************************************
 *
 * I2C interface
 *
 * There are multiple devices connected to I2C peripheral:
 *  - Codec ES8311 (configuration only)
 *  - LCD Touch controller
 **************************************************************************************************/
#define BSP_I2C_NUM     CONFIG_BSP_I2C_NUM

/**
 * @brief Init I2C driver
 *
 * @return
 *      - ESP_OK                On success
 *      - ESP_ERR_INVALID_ARG   I2C parameter error
 *      - ESP_FAIL              I2C driver installation error
 *
 */
esp_err_t bsp_i2c_init(void);

/**
 * @brief Deinit I2C driver and free its resources
 *
 * @return
 *      - ESP_OK                On success
 *      - ESP_ERR_INVALID_ARG   I2C parameter error
 *
 */
esp_err_t bsp_i2c_deinit(void);

/**
 * @brief Get I2C driver handle
 *
 * @return
 *      - I2C handle
 *
 */
i2c_master_bus_handle_t bsp_i2c_get_handle(void);

/**************************************************************************************************
 *
 * I2S audio interface
 *
 * There are two devices connected to the I2S peripheral:
 *  - Codec ES8311 for output(playback) and input(recording) path
 *
 * For speaker initialization use bsp_audio_codec_speaker_init() which is inside initialize I2S with bsp_audio_init().
 * For microphone initialization use bsp_audio_codec_microphone_init() which is inside initialize I2S with bsp_audio_init().
 * After speaker or microphone initialization, use functions from esp_codec_dev for play/record audio.
 * Example audio play:
 * \code{.c}
 * esp_codec_dev_set_out_vol(spk_codec_dev, DEFAULT_VOLUME);
 * esp_codec_dev_open(spk_codec_dev, &fs);
 * esp_codec_dev_write(spk_codec_dev, wav_bytes, bytes_read_from_spiffs);
 * esp_codec_dev_close(spk_codec_dev);
 * \endcode
 **************************************************************************************************/
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

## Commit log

2025-09-25 add esp_brookesia_phone
    [partitions.csv]
2025-09-28 add docs
    [MaTouch ESP32-P4 TFT with Touch 7“ V1.2.brd, MaTouch ESP32-P4 TFT with Touch 7“ V1.2.sch]
2025-09-28 add hardware&datasheet
    [MaTouch ESP32-P4 TFT with Touch 7“ V1.2.brd, MaTouch ESP32-P4 TFT with Touch 7“ V1.2.sch]

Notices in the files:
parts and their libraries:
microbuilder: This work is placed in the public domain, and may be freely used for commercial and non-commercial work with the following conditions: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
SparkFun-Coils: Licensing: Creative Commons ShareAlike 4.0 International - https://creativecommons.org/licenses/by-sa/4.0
